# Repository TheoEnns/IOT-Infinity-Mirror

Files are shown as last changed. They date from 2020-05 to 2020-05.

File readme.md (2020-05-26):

## IOT Infinity Mirror

A wall mounted infinity mirror with IOT control integrated into google home assistant using IFTTT and Adafruit IOT plugins

## Getting Started and Installing

You will need to create you own SecretConfig.h file of the format:

---
    #pragma once

    #define AIO_SERVERPORT 1883  
    #define AIO_SERVER      "io.adafruit.com"
    #define AIO_KEY       ""
    #define DEVICE_NAME ""
    #define AIO_USERNAME  ""
    #define SECRET_SSID ""
    #define SECRET_PASS ""
---

### Prerequisite parts

This project uses the following equipment:
* 3D printed parts located in the parts folder
* [Arduino Nano 33 IoT with headers Mounted](https://www.amazon.com/gp/product/B07WPFQZQ1) - Arduino Board wioth built in Wifi
* [Nano Breakout Mount](https://www.amazon.com/gp/product/B072FCNF54)
* [SparkFun Qwiic Keypad - 12 Button](https://www.sparkfun.com/products/15290) - This keypad is for manual control as backup (optional)
* 2x [WS2812B RGB 5050SMD Individual Addressable 3.3FT 144](https://www.amazon.com/gp/product/B01CDTEJR0/) - High Density LED String
* [5V 15A AC to DC Power Supply Adapter](https://www.amazon.com/gp/product/B01LXN7MN3/) - power supply
* [Semi-Transparent 12 inch acrylic mirror](https://www.amazon.com/gp/product/B07XTRC7F1/) - Van be cit via dremel to round shape. Doesn't look great though due to bending and poor clean-ability
* [Semi-Transparent 12 inch glass mirror](https://www.twowaymirrors.com/glass/) - Thanks to the great folk at Two Way Mirrors for the semi-transparent mirror! This could be replaced by cheaper acrylic two way mirror on amazon (which I initially used), but glass looks much cooler!

Some soldering and M3 screws required.

## Running the tests

Example animation commands:

    Hey Google, set mirror rainbow

    Okay Google, mirror clock

    Okay Google, mirror off

Commands can take the form(s)

    (Okay,Hey) Google, (mirror,set mirror,magic mirror) $

where the command $ includes

    "rainbow", 
    "rainbow chase",
    "clock",
    "white red",
    "white blue",
    "white green",
    "white purple",
    "white black",
    "off",
    "on",
    "chase red",
    "chase blue",
    "chase green",
    "chase purple",
    "alignment",
    "brighten",
    "dim",
    "reverse",
    "counter"

## Built With

* [IFTTT](https://ifttt.com/) - This links Google Assistant commands to push commands to Adafruit IO servers
* [Adafruit IO](https://io.adafruit.com/) - Free web proprerties hosting with dashboard plugins and http query API
* [Google Assistant](https://assistant.google.com/) - Feel free to replace with Alexa, Siri, or your prefered IOT voice system

## Authors

* **Theodore Enns** - [Check out my youtube channel!](https://www.youtube.com/channel/UCWVNKVqwlDwOcAsUMM4TJnA)

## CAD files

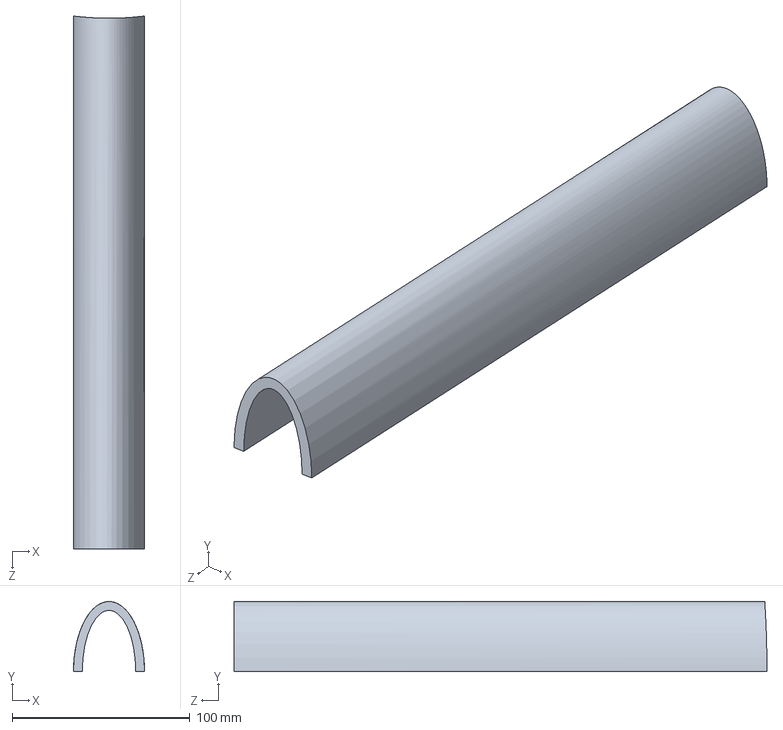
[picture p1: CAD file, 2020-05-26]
parts/Wire Guide.SLDPRT
40.0 x 39.4 x 299.7 mm

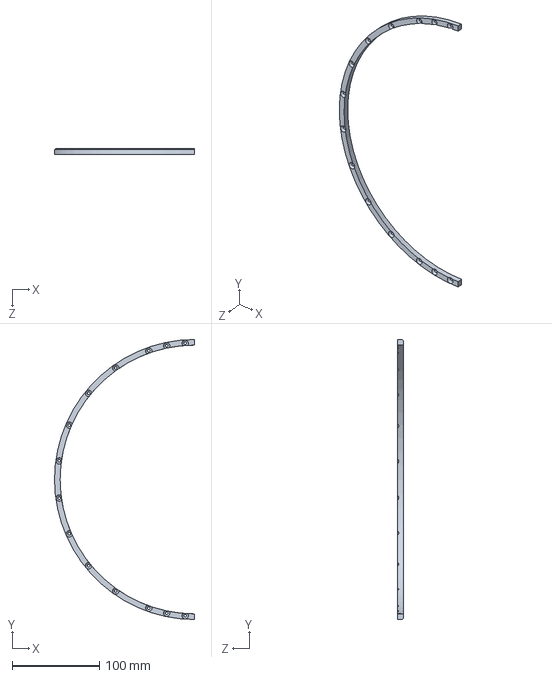
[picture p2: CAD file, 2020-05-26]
parts/Half Glass Mirror Spacer Ring.SLDPRT
160.4 x 320.8 x 6.35 mm

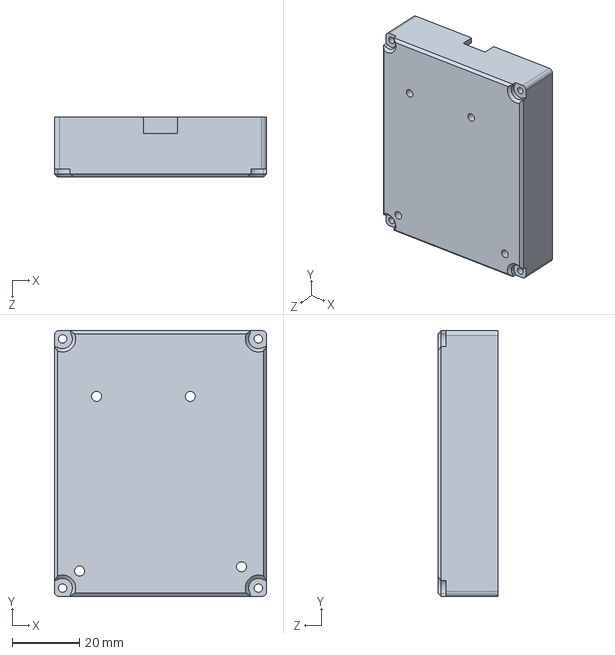
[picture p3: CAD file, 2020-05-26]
parts/CB Bottom Contianer.SLDPRT
63.3 x 79.3 x 18.0 mm

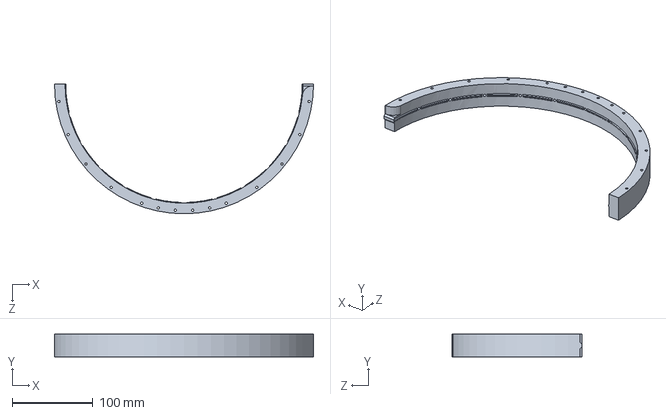
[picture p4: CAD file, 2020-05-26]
parts/Ring Seperator.SLDPRT
320.8 x 28.0 x 160.4 mm

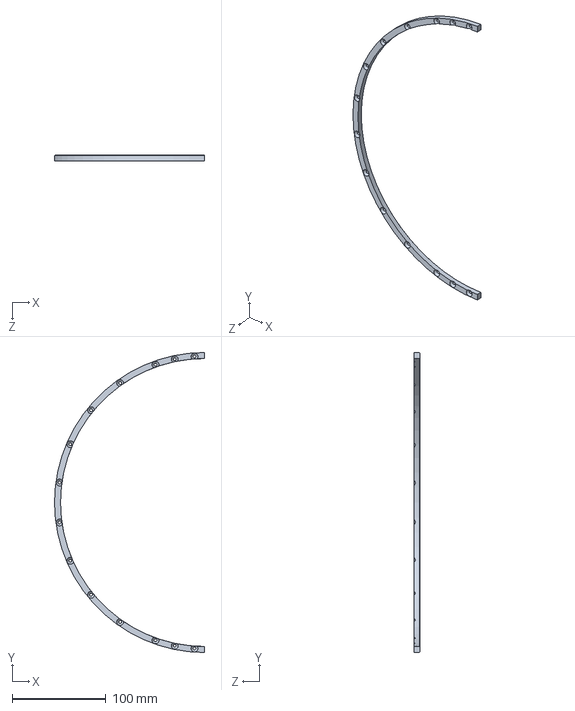
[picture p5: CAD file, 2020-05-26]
parts/Half Glass Mirror Spacer Ring v2.SLDPRT
160.4 x 320.8 x 6.00 mm

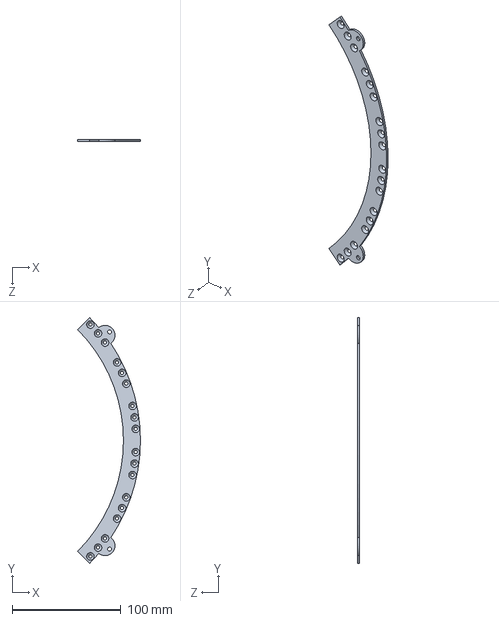
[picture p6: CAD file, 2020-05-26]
parts/Wall Exterior Rim Quarter .sldprt
58.0 x 226.6 x 2.00 mm

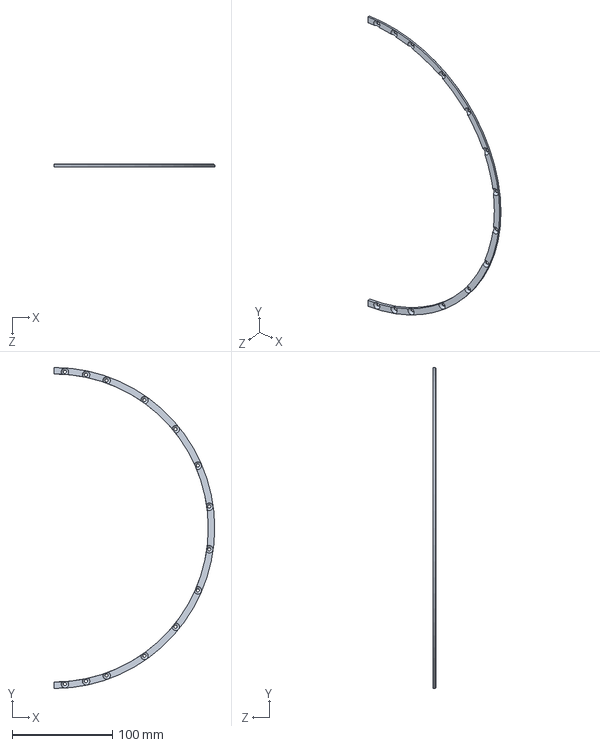
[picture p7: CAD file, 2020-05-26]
parts/Half Acrylic Mirror Spacer Ring.SLDPRT
160.4 x 320.8 x 3.05 mm

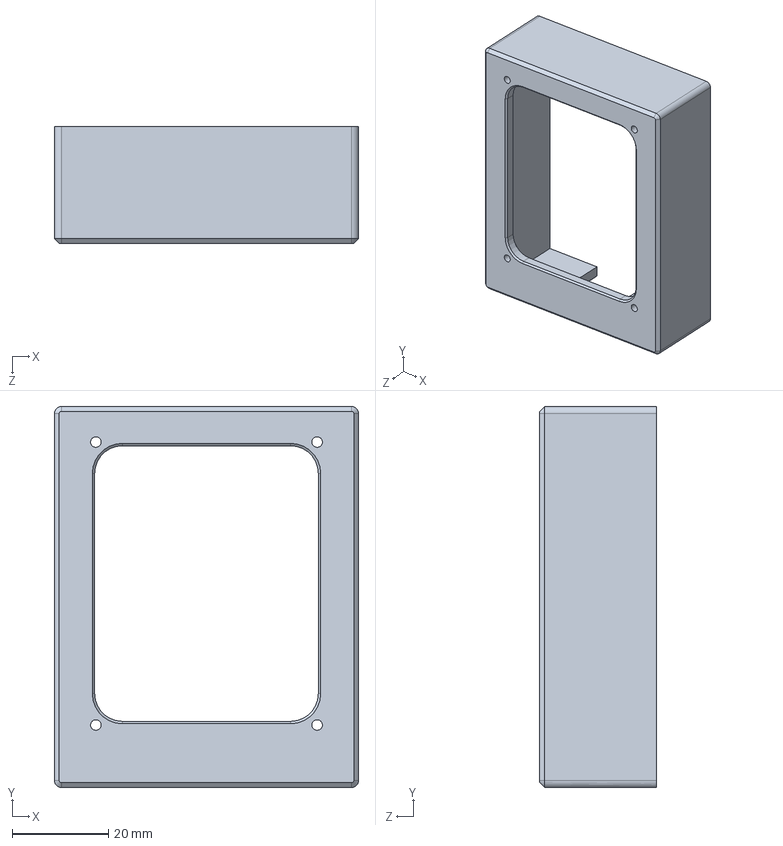
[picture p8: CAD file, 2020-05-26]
parts/CB Top Lid.SLDPRT
63.3 x 79.3 x 24.3 mm

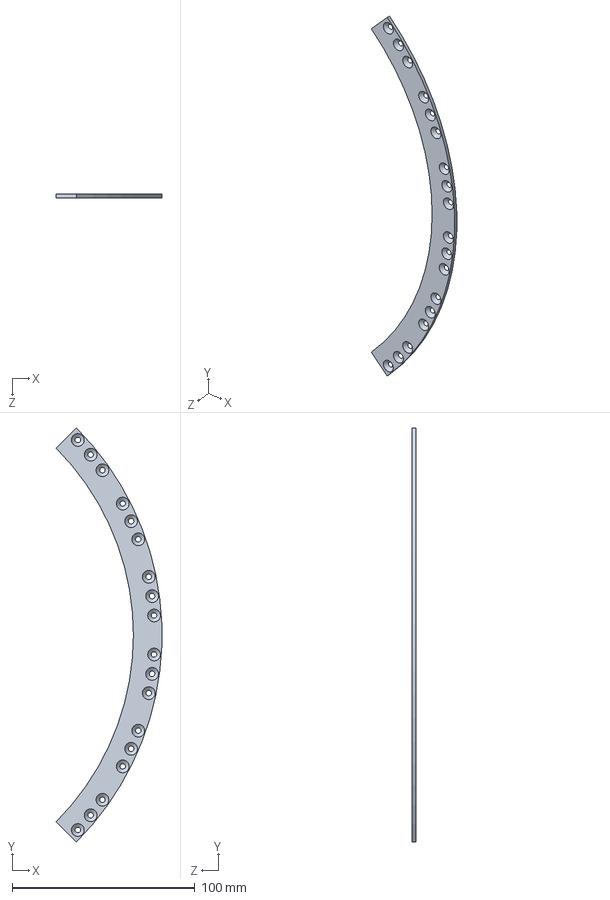
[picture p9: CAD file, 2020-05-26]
parts/Exterior Rim Quarter.sldprt
57.8 x 226.6 x 2.00 mm

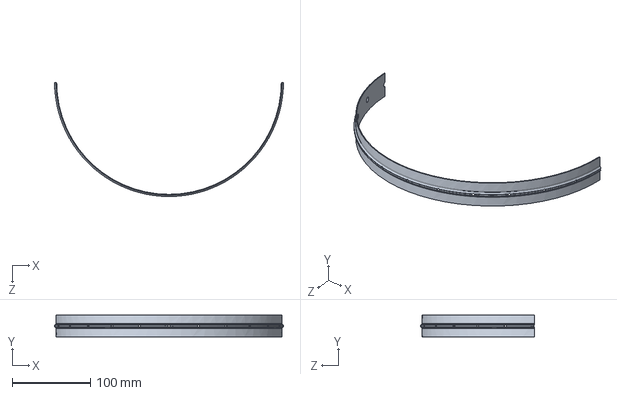
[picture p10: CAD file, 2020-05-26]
parts/Transparent Inner Ring.SLDPRT
293.0 x 28.0 x 146.0 mm

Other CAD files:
parts/CB Top Lid.STL
parts/Exterior Rim Quarter.STL
parts/Half Acrylic Mirror Spacer Ring.STL
parts/Half Glass Mirror Spacer Ring v2.STL
parts/Half Glass Mirror Spacer Ring.STL
parts/Wall Exterior Rim Quarter .STL
parts/Wire Guide.STL

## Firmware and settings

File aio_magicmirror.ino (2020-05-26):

#include <Wire.h>
#include <SPI.h>

/************************
 *  Control Commands
 ************************/
bool commandEvent = false;
int commandCode = 0;
int currentChoice = 0;
using animation_func = void(*)(); //cycle time
void doNothing(){}
animation_func animation = doNothing;
int num_commands = 19;
String myTextCommands[] = {
  "rainbow",
  "rainbow chase",
  "clock",
  "white red",
  "white blue",
  "white green",
  "white purple",
  "white black",
  "off",
  "on",
  "chase red",
  "chase blue",
  "chase green",
  "chase purple",
  "alignment",
  "brighten",
  "dim",
  "reverse",
  "counter"
};
#include "thumbpad.h"

/************************
 *  Personal Data
 ************************/
#include "SecretConfig.h"
/* 
// Includes from tsecretConfig.h
#define AIO_SERVERPORT  1883
#define AIO_SERVER      "io.adafruit.com"
#define AIO_KEY       "Adafruit IO Key"
#define DEVICE_NAME   "Magic_Mirror_Device"
#define AIO_USERNAME  "user account"
#define tsecRET_SSID   "mySSID"
#define tsecRET_PASS   "password"
*/
// See https://io.adafruit.com/ for web server hosting
// See https://ifttt.com/applets/ for Google Assistant triggers


/************************
 *  Wifi Server
 ************************/
 #include "WifiConnection.h"

/************************
 *  IOT Subscription And Publishing
 ************************/
 #include "IOT_Functions.h"

/************************
 *  Update cycle configuration
 ************************/
 #include "Neopixel_Animation.h"
unsigned long updateCylceTime = 5; // how many millis per polling cycle
unsigned long network_interval = 5000;
unsigned long network_timer = 0;

/************************
 *  Animation Control
 ************************/
#include "Neopixel_Animation.h"

/************************
 *  connection agent
 ************************/
 // Checks for cannnectivity and starts/restarts connections if needed
bool Ensure_Connections(){
  wstatus = WiFi.status();
  if(wstatus != WL_CONNECTED) {
    mqtt.disconnect();
    wifi_setup();
  }
  if(! mqtt.connected()) {
    mqtt.disconnect();
    IOT_Setup();
  }
  return (wstatus == WL_CONNECTED && mqtt.connected());
}

/************************
 *  main program
 ************************/
void processCommands(){
  if(! commandEvent)
    return;
  commandEvent = false;
  if(commandCode<0 || commandCode>=num_commands)
    return;
  cycle = 0;
  Serial.println("switching to command: ");
  switch(commandCode){
    case 0:
      Serial.println("rainbow");
      animSpeed = 1;
      animation = rainbow;
      break;
    case 1:
      Serial.println("rainbow chase");
      animSpeed = 2;
      animation = theaterChaseRainbow;
      break;
    case 2:
      Serial.println("clock");
      anim_direction_f_cw = true;
      anim_direction_b_cw = true;
      animSpeed = 1;
      animation = Clock_Animation;
      break;
    case 3:
      Serial.println("wipe red");
      animSpeed = 1;
      colors[0] = MColor(255,0,0);
      animation = colorWipe;
      break;
    case 4:
      Serial.println("wipe blue");
      animSpeed = 1;
      colors[0] = MColor(0,0,255);
      animation = colorWipe;
      break;
    case 5:
      Serial.println("wipe green");
      animSpeed = 1;
      colors[0] = MColor(0,255,0);
      animation = colorWipe;
      break;
    case 6:
      Serial.println("wipe purple");
      animSpeed = 1;
      colors[0] = MColor(255,0,255);
      animation = colorWipe;
      break;
    case 7:
      Serial.println("wipe black");
      anim_direction_f_cw = true;
      anim_direction_b_cw = true;
      animSpeed = 1;
      colors[0] = MColor(0,0,0);
      animation = colorWipe;
      break;
    case 8:
      Serial.println("off");
      if(currentChoice != 8){
        anim_direction_f_cw = true;
        anim_direction_b_cw = true;
        animSpeed = 1;
        Set_Brightness(150);
        Clear();
        Display_Update();
        animation = doNothing;
      }
      break;
    case 9:
      Serial.println("on");
      Set_Brightness(150);
      if(currentChoice == 8 || currentChoice == 7){
        animSpeed = 1;
        animation = rainbow;
      }
      break;
    case 10:
      Serial.println("red chase");
      animSpeed = 2;
      colors[0] = MColor(255,0,0);
      animation = theaterChase;
      break;
    case 11:
      Serial.println("blue chase");
      animSpeed = 2;
      colors[0] = MColor(0,0,255);
      animation = theaterChase;
      break;
    case 12:
      Serial.println("green chase");
      animSpeed = 2;
      colors[0] = MColor(0,255,0);
      animation = theaterChase;
      break;
    case 13:
      Serial.println("purple chase");
      animSpeed = 2;
      colors[0] = MColor(255,0,255);
      animation = theaterChase;
      break;
    case 14:
      Serial.println("alingment");
      animSpeed = 1;
      animation = Red_Light_Tracing;
      break;
    case 15:
      Serial.println("brighten");
      Set_Brightness(brightness + 50);
      break;
    case 16:
      Serial.println("dim");
      Set_Brightness(brightness - 50);
      break;
    case 17:
      Serial.println("reverse");
      anim_direction_f_cw = !anim_direction_f_cw;
      anim_direction_b_cw = !anim_direction_b_cw;
      break;
    case 18:
      Serial.println("counter");
      anim_direction_b_cw = !anim_direction_b_cw;
      break;
  }
  currentChoice = commandCode;
}
 
void setup() {
  stripF.begin(); 
  stripF.show(); 
  stripF.setBrightness(brightness); 
  stripB.begin();  
  stripB.show();    
  stripB.setBrightness(brightness); 
  Serial.begin(2000000);
  delay(500);
  setupKeypad();

  Serial.println("Magic Mirror Starting ...");
  bool success = Ensure_Connections();
  if (success){
    Serial.println("Magic Mirror Started\n");
  }else{
    Serial.println("Magic Mirror Failed To Start\n");
  }

  Set_Brightness(brightness);
  network_timer = millis()+network_interval;
  heartbeat = false;
  animation = rainbow;
}

void loop() {  
  Ensure_Connections();

  mqtt.processPackets(updateCylceTime); //Delay to read packets
  checkButtons();
  processCommands();
  
  animation();

  if(network_timer < millis()){
    if(! heartbeat){
      mqtt.disconnect();
    }// Seems completely unessecary if you use heartbeat monitoring
//  else if(! mqtt.ping()) {
//    // Note pings can stop this code from working if done too often
//    mqtt.disconnect();
//  }
    heartbeat = false;
    network_timer = millis()+network_interval;
  }else if(network_timer >= millis()+network_interval*2){
    network_timer = millis()+network_interval; // rollover protection
  }
}

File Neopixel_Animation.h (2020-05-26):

#pragma once

#include <Adafruit_NeoPixel.h>
#include <Wire.h>
#include <SPI.h>

//Pin / LED Config
static const int FRONT_STRIP = 0;
static const int BACK_STRIP = 1;
static const int LED_PIN_FRONT = 10;
static const int LED_PIN_BACK = 9;
static const int LED_COUNT = 135;
static const int LED_Start = 2;
static const int LED_End = 135;
static const int LEDF_Offset = 0;
static const int LEDB_Offset = -4;
static const int ACTIVE_LED_COUNT = 133; // LED_COUNT - LED_Start

int brightness = 150;
float animSpeed = 1;
bool anim_direction_f_cw = true;
bool anim_direction_b_cw = true;

// Declare our NeoPixel strip object:
Adafruit_NeoPixel stripF(LED_COUNT, LED_PIN_FRONT, NEO_GRB + NEO_KHZ800);
Adafruit_NeoPixel stripB(LED_COUNT, LED_PIN_BACK, NEO_GRB + NEO_KHZ800);
long cycle = 0; // used for animation phases
double cursorWidth = 0.008333; // Size of clock cursor

uint32_t colors[24];

/************************
 *  RAW LED CONTROL
 ************************/
void Clear(){
  stripF.clear();
  stripB.clear();
}

void Set_Brightness(int _brightness){
  brightness = constrain(_brightness,0,200);    
  stripF.setBrightness(brightness); // (max = 255)
  stripB.setBrightness(brightness); // (max = 255)                     
}

int Get_Brightness(){
  return brightness ;                   
}

uint32_t MColor(int _red, int _green,int _blue){
    //  Color(255,   0,   0) // Red
    //  Color(  0, 255,   0) // Green
    //  Color(  0,   0, 255) // Blue
  return stripF.Color(
      constrain(_red,0,255),
      constrain(_green,0,255), 
      constrain(_blue,0,255)
      );
}

int index2Address(int index){
  return constrain((index)%(LED_End-LED_Start)+LED_Start,LED_Start,LED_COUNT);
}

int reverseIndex(int index){
  return constrain(ACTIVE_LED_COUNT-index,0,ACTIVE_LED_COUNT);
}

float Get_Index_From_Angle(float angle, int strip){
  if(strip == FRONT_STRIP){
    return constrain((ACTIVE_LED_COUNT * (angle/360.0f)),0,ACTIVE_LED_COUNT-1);
  }else if(strip == BACK_STRIP){
    return constrain((ACTIVE_LED_COUNT * (angle/360.0f)),0,ACTIVE_LED_COUNT-1);
  }
  return -1;
}

void Set_Pixel_By_Index(int index, int strip, uint32_t color){
  if(strip == FRONT_STRIP){
    if(!anim_direction_f_cw){
      index = ACTIVE_LED_COUNT - index;
    }
    stripF.setPixelColor(index2Address(             (index)%ACTIVE_LED_COUNT), color);
  }else if(strip == BACK_STRIP){
    if(!anim_direction_b_cw){
      index = ACTIVE_LED_COUNT - index;
    }
    stripB.setPixelColor(index2Address(reverseIndex((index+4)%ACTIVE_LED_COUNT)), color);
  }
}

void Set_Pixel_By_Angle(float angle, int strip, uint32_t color){
  float index = Get_Index_From_Angle( angle,  strip);
  Set_Pixel_By_Index(round(index), strip, color);
}

void Display_Update(){
  stripF.show();
  stripB.show();
}

int Get_MAX_Index(){
  return ACTIVE_LED_COUNT;
}

/************************
 *  Classic Neopixel Animations
 ************************/
void rainbow() {
  // replacing for(long cycle = 0; cycle < 5*65536; cycle += 256)
  cycle += 256*animSpeed;
  if(cycle >= 5*65536)
    cycle = 0;
//  Serial.println( cycle + (1 * 65536L / Get_MAX_Index()) );
  for(int i=0; i<Get_MAX_Index(); i++) { 
    int pixelHue = cycle + (i * 65536L / Get_MAX_Index());
    Set_Pixel_By_Index(i, FRONT_STRIP, stripF.gamma32(stripF.ColorHSV(pixelHue)));
    Set_Pixel_By_Index(i, BACK_STRIP, stripF.gamma32(stripF.ColorHSV(pixelHue)));
  }
  Display_Update();
}

void theaterChaseRainbow() {
  int firstPixelHue = 0;
  cycle = (cycle+1)%(30*((int)animSpeed));

  int a = (cycle/((int)animSpeed))%10;    
  int b = (cycle/((int)animSpeed))%3;    
  Clear();         //   Set all pixels in RAM to 0 (off)
  // 'c' counts up from 'b' to end of strip in steps of 3...
  for(int c=b; c<Get_MAX_Index(); c += 3) {
    int hue   = firstPixelHue + c * 65536L / Get_MAX_Index();
    uint32_t color = stripF.gamma32(stripF.ColorHSV(hue)); // hue -> RGB
    Set_Pixel_By_Index(c, FRONT_STRIP, color);
    Set_Pixel_By_Index(c, BACK_STRIP, color);
  }
  Display_Update(); // Update strip with new contents
}

void theaterChase() {
  cycle = (cycle+1)%(30*((int)animSpeed));

  int a = (cycle/((int)animSpeed))%10;    
  int b = (cycle/((int)animSpeed))%3;    
  Clear();         //   Set all pixels in RAM to 0 (off)
  // 'c' counts up from 'b' to end of strip in steps of 3...
  for(int c=b; c<Get_MAX_Index(); c += 3) {
    Set_Pixel_By_Index(c, FRONT_STRIP, colors[0]);
    Set_Pixel_By_Index(c, BACK_STRIP, colors[0]);
  }
  Display_Update(); // Update strip with new contents
}

void colorWipe() {
  cycle = (cycle+1)%(Get_MAX_Index()*((int)animSpeed));
  int pi = (cycle)/((int)animSpeed);

  Set_Pixel_By_Index(pi, FRONT_STRIP, colors[0]);
  Set_Pixel_By_Index(pi, BACK_STRIP, colors[0]);
  Display_Update();                          //  Update strip to match
}

/************************
 *  Custom Animations
 ************************/

//Description: Used to sync front and back LED Strips. 
//   Cycles a red light in a circle across a background of blue then green lines.
void Red_Light_Tracing(){
  cycle = (cycle+1)%(Get_MAX_Index()*((int)animSpeed));
  for(int i=0;i<Get_MAX_Index();i++){
    Set_Pixel_By_Index(i, FRONT_STRIP, MColor(0, (i%2)==1?255:0, (i%2)==1?0:255));
    Set_Pixel_By_Index(i, BACK_STRIP, MColor(0, (i%2)==1?255:0, (i%2)==1?0:255));
  }
  Set_Pixel_By_Index(cycle/animSpeed, FRONT_STRIP, MColor(255, 0, 0));
  Set_Pixel_By_Index(cycle/animSpeed, BACK_STRIP, MColor(255, 0, 0));
  Display_Update();
}

void Clock_Animation(){   
  double curTime = (millis()/1000.0) - time_diff; 
  double hours = fmod(curTime,86400.0) / 3600.0;
  double minutes = fmod(curTime,3600.0) / 60.0;
  double seconds = fmod(curTime,60.0);
  int red, redB, fade;
  int blue, blueB;
  int green, greenB;

  cycle = (cycle+1)%(120*((int)animSpeed));
  fade = (cycle/((int)animSpeed))%120;
  fade = fade>60 ? 120 - fade: fade;
  double fractionS = seconds/60.0; 
  double fractionM = minutes/60.0;
  double fractionH = fmod(hours,12.0)/12.0;
  for(int i=0;i<Get_MAX_Index();i++){
    double fraction = fmod(((double)i+1)/((double)Get_MAX_Index())+0.5,1.0);
    if( (i+1)%(Get_MAX_Index()/12)==0){
      red = blue = green = 150; 
    }else{
      red = blue = green = fade;
    }
    
    double distS = fmin(fabs(fractionS - fraction),fabs(fraction-fractionS));
    double distM = fmin(fabs(fractionM - fraction),fabs(fraction-fractionM));
    double distH = fmin(fabs(fractionH - fraction),fabs(fraction-fractionH));
    
    if(distS < cursorWidth){
      red += 255.0*(cursorWidth - distS)/cursorWidth;
    }
    if(distM < 2*cursorWidth){
      blue += 255.0*(2*cursorWidth - distM)/cursorWidth;
    }
    if(distH < 3*cursorWidth){
      green += 255.0*(3*cursorWidth - distH)/cursorWidth;
    }
    
    Set_Pixel_By_Index(i, FRONT_STRIP, MColor(red, blue, green));
    Set_Pixel_By_Index(i, BACK_STRIP, MColor(red, blue, green));
  }
  Display_Update();
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
